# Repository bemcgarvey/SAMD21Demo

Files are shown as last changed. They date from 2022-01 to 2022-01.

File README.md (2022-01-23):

# SAMD21Demo
 
## A demonstartion board for the ATSAMD21G18A microcontroller.  Includes firmware projects to demonstrate many modules and features.  
  
### There is sample firmware for:
* Basic gpio and interrupts
* Sleepwalking
* Analog comparator
* PWM h-bridge control
* USB MSD device
* I2C LCD

### All firmware is built in MPLabX with MPLab Harmony 3 and the XC32 compiler.  
### Schematic and PCB were made with KiCAD

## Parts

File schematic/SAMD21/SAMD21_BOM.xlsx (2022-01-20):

Ref | Qnty | Value | Footprint
C1, C2, C4, C6, | 4 | 100n | Capacitor_SMD:C_0402_1005Metric
C3, | 1 | 10uF | Capacitor_SMD:C_0805_2012Metric
C5, | 1 | 22uF | Capacitor_SMD:C_0603_1608Metric
C7, | 1 | 1 uF | Capacitor_SMD:C_0402_1005Metric
C8, | 1 | 100n | Capacitor_SMD:C_0603_1608Metric
C9, | 1 | 220n | Capacitor_SMD:C_0603_1608Metric
D1, | 1 | Red | LED_SMD:LED_0603_1608Metric
D2, | 1 | Red | LED_SMD:LED_0805_2012Metric
D3, D4, | 2 | MBR0520LT | Diode_SMD:D_SOD-123
D5, | 1 | Yellow | LED_SMD:LED_0805_2012Metric
D6, | 1 | Blue | LED_SMD:LED_0805_2012Metric
D7, | 1 | Green | LED_SMD:LED_0805_2012Metric
D8, | 1 | Green | LED_SMD:LED_0603_1608Metric
D9, | 1 | Yellow | LED_SMD:LED_0603_1608Metric
IC1, | 1 | ATSAMD21G18A-AU | SamacSys_Parts:QFP50P900X900X120-48N
IC2, | 1 | AZ1117IH-3.3TRG1 | SamacSys_Parts:SOT230P700X180-4N
IC3, | 1 | MCP2221-I_SL | SamacSys_Parts:SOIC127P600X175-14N
J1, | 1 | Barrel_Jack_Switch | Connector_BarrelJack:BarrelJack_Wuerth_6941xx301002
J2, | 1 | Power | Connector_PinHeader_2.54mm:PinHeader_2x03_P2.54mm_Vertical
J3, J4, J7, J13, | 4 | Conn_01x02 | Connector_PinHeader_2.54mm:PinHeader_1x02_P2.54mm_Vertical
J5, | 1 | USB_B_Micro | Connector_USB:USB_Micro-B_Amphenol_10118194_Horizontal
J6, | 1 | USB_B_Mini | Connector_USB:USB_Mini-B_Wuerth_65100516121_Horizontal
J8, J9, | 2 | Conn_02x02_Odd_Even | Connector_PinHeader_2.54mm:PinHeader_2x02_P2.54mm_Vertical
J10, J11, J12, | 3 | Conn_02x06_Odd_Even | Connector_PinHeader_2.54mm:PinHeader_2x06_P2.54mm_Vertical
J14, | 1 | Conn_02x05_Odd_Even | Connector_PinHeader_2.54mm:PinHeader_2x05_P2.54mm_Vertical
J15, | 1 | Conn_01x08 | Connector_PinHeader_2.54mm:PinHeader_1x08_P2.54mm_Horizontal
L1, | 1 | 470R | Inductor_SMD:L_0603_1608Metric
R1, | 1 | 100k | Resistor_SMD:R_0603_1608Metric
R2, R5, R6, R8, R11, R12, | 6 | 220R | Resistor_SMD:R_0603_1608Metric
R3, | 1 | 15k | Resistor_SMD:R_0603_1608Metric
R4, | 1 | 22k | Resistor_SMD:R_0603_1608Metric
R7, | 1 | 62R | Resistor_SMD:R_0603_1608Metric
R9, | 1 | 10k | Resistor_SMD:R_0603_1608Metric
R10, R13, | 2 | 4k7 | Resistor_SMD:R_0603_1608Metric
R14, | 1 | 1k | Resistor_SMD:R_0603_1608Metric
SW1, | 1 | SW_MEC_5E | SamacSys_Parts:PTS647SK38SMTR2LFS
SW2, SW3, | 2 | SW_MEC_5E | SamacSys_Parts:FSM16JH

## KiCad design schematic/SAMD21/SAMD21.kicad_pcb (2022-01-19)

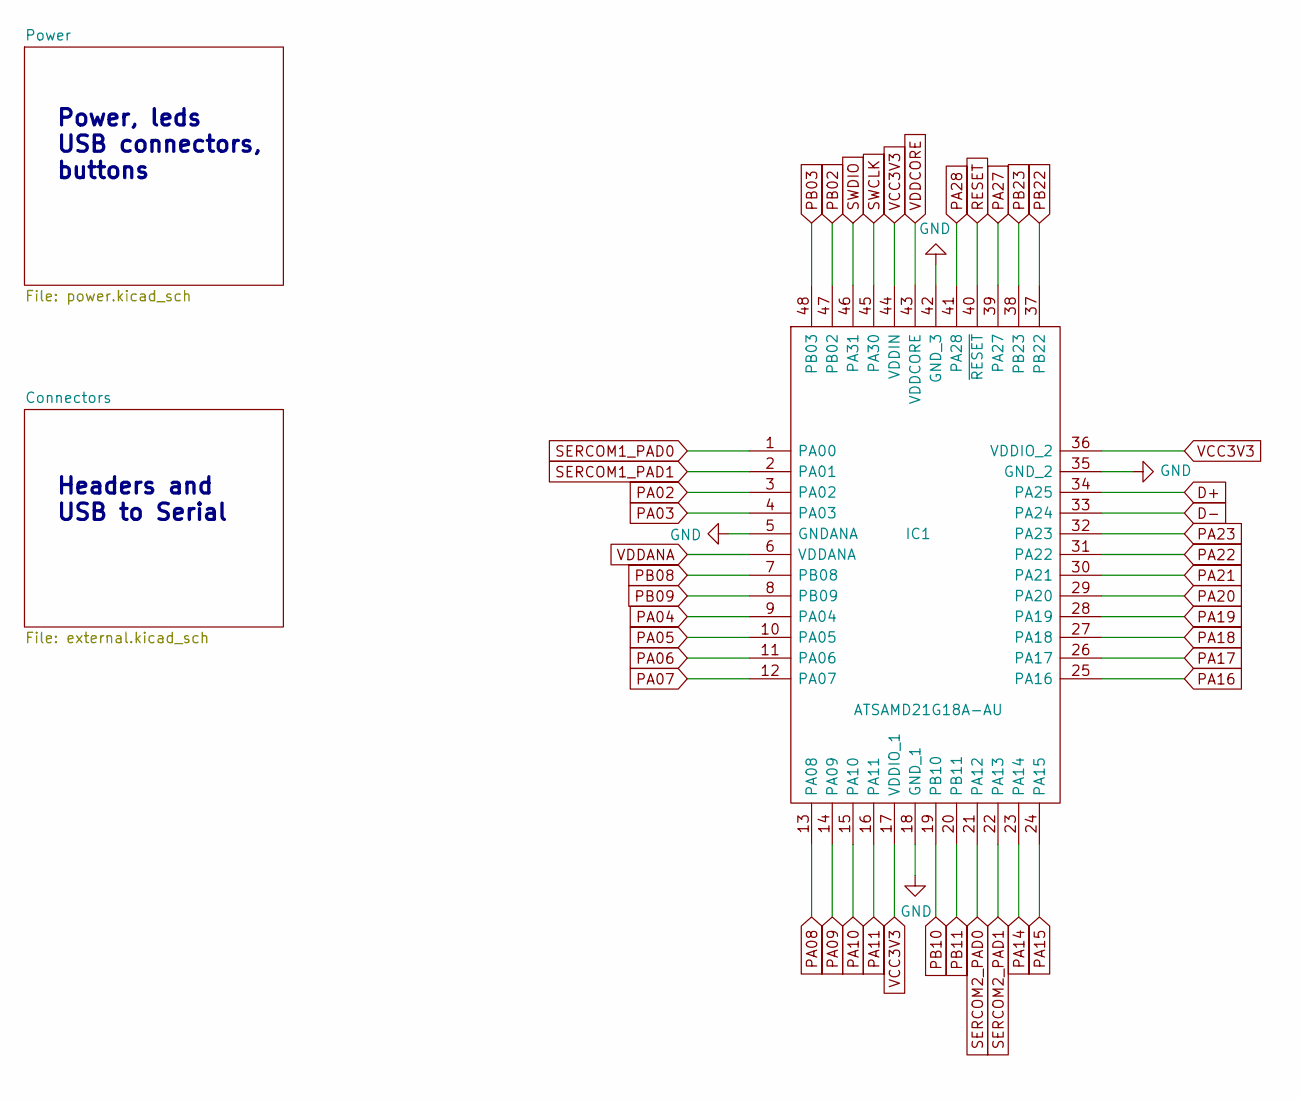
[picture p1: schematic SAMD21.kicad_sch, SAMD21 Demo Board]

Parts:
IC1: ATSAMD21G18A-AU; QFP50P900X900X120-48N; Mouser Part Number 556-ATSAMD21G18A-AU

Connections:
D+: IC1.34 (PA25); also elsewhere on the board
D-: IC1.33 (PA24); also elsewhere on the board
GND: IC1.5 (GNDANA), IC1.18 (GND_1), IC1.35 (GND_2), IC1.42 (GND_3); also elsewhere on the board
PA02: IC1.3 (PA02); also elsewhere on the board
PA03: IC1.4 (PA03); also elsewhere on the board
PA04: IC1.9 (PA04); also elsewhere on the board
PA05: IC1.10 (PA05); also elsewhere on the board
PA06: IC1.11 (PA06); also elsewhere on the board
PA07: IC1.12 (PA07); also elsewhere on the board
PA08: IC1.13 (PA08); also elsewhere on the board
PA09: IC1.14 (PA09); also elsewhere on the board
PA10: IC1.15 (PA10); also elsewhere on the board
PA11: IC1.16 (PA11); also elsewhere on the board
PA14: IC1.23 (PA14); also elsewhere on the board
PA15: IC1.24 (PA15); also elsewhere on the board
PA16: IC1.25 (PA16); also elsewhere on the board
PA17: IC1.26 (PA17); also elsewhere on the board
PA18: IC1.27 (PA18); also elsewhere on the board
PA19: IC1.28 (PA19); also elsewhere on the board
PA20: IC1.29 (PA20); also elsewhere on the board
PA21: IC1.30 (PA21); also elsewhere on the board
PA22: IC1.31 (PA22); also elsewhere on the board
PA23: IC1.32 (PA23); also elsewhere on the board
PA27: IC1.39 (PA27); also elsewhere on the board
PA28: IC1.41 (PA28); also elsewhere on the board
PB02: IC1.47 (PB02); also elsewhere on the board
PB03: IC1.48 (PB03); also elsewhere on the board
PB08: IC1.7 (PB08); also elsewhere on the board
PB09: IC1.8 (PB09); also elsewhere on the board
PB10: IC1.19 (PB10); also elsewhere on the board
PB11: IC1.20 (PB11); also elsewhere on the board
PB22: IC1.37 (PB22); also elsewhere on the board
PB23: IC1.38 (PB23); also elsewhere on the board
RESET: IC1.40 (~RESET); also elsewhere on the board
SERCOM1_PAD0: IC1.1 (PA00); also elsewhere on the board
SERCOM1_PAD1: IC1.2 (PA01); also elsewhere on the board
SERCOM2_PAD0: IC1.21 (PA12); also elsewhere on the board
SERCOM2_PAD1: IC1.22 (PA13); also elsewhere on the board
SWCLK: IC1.45 (PA30); also elsewhere on the board
SWDIO: IC1.46 (PA31); also elsewhere on the board
VCC3V3: IC1.17 (VDDIO_1), IC1.36 (VDDIO_2), IC1.44 (VDDIN); also elsewhere on the board
VDDANA: IC1.6 (VDDANA); also elsewhere on the board
VDDCORE: IC1.43 (VDDCORE); also elsewhere on the board

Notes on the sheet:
Headers and USB to Serial
Power, leds USB connectors, buttons

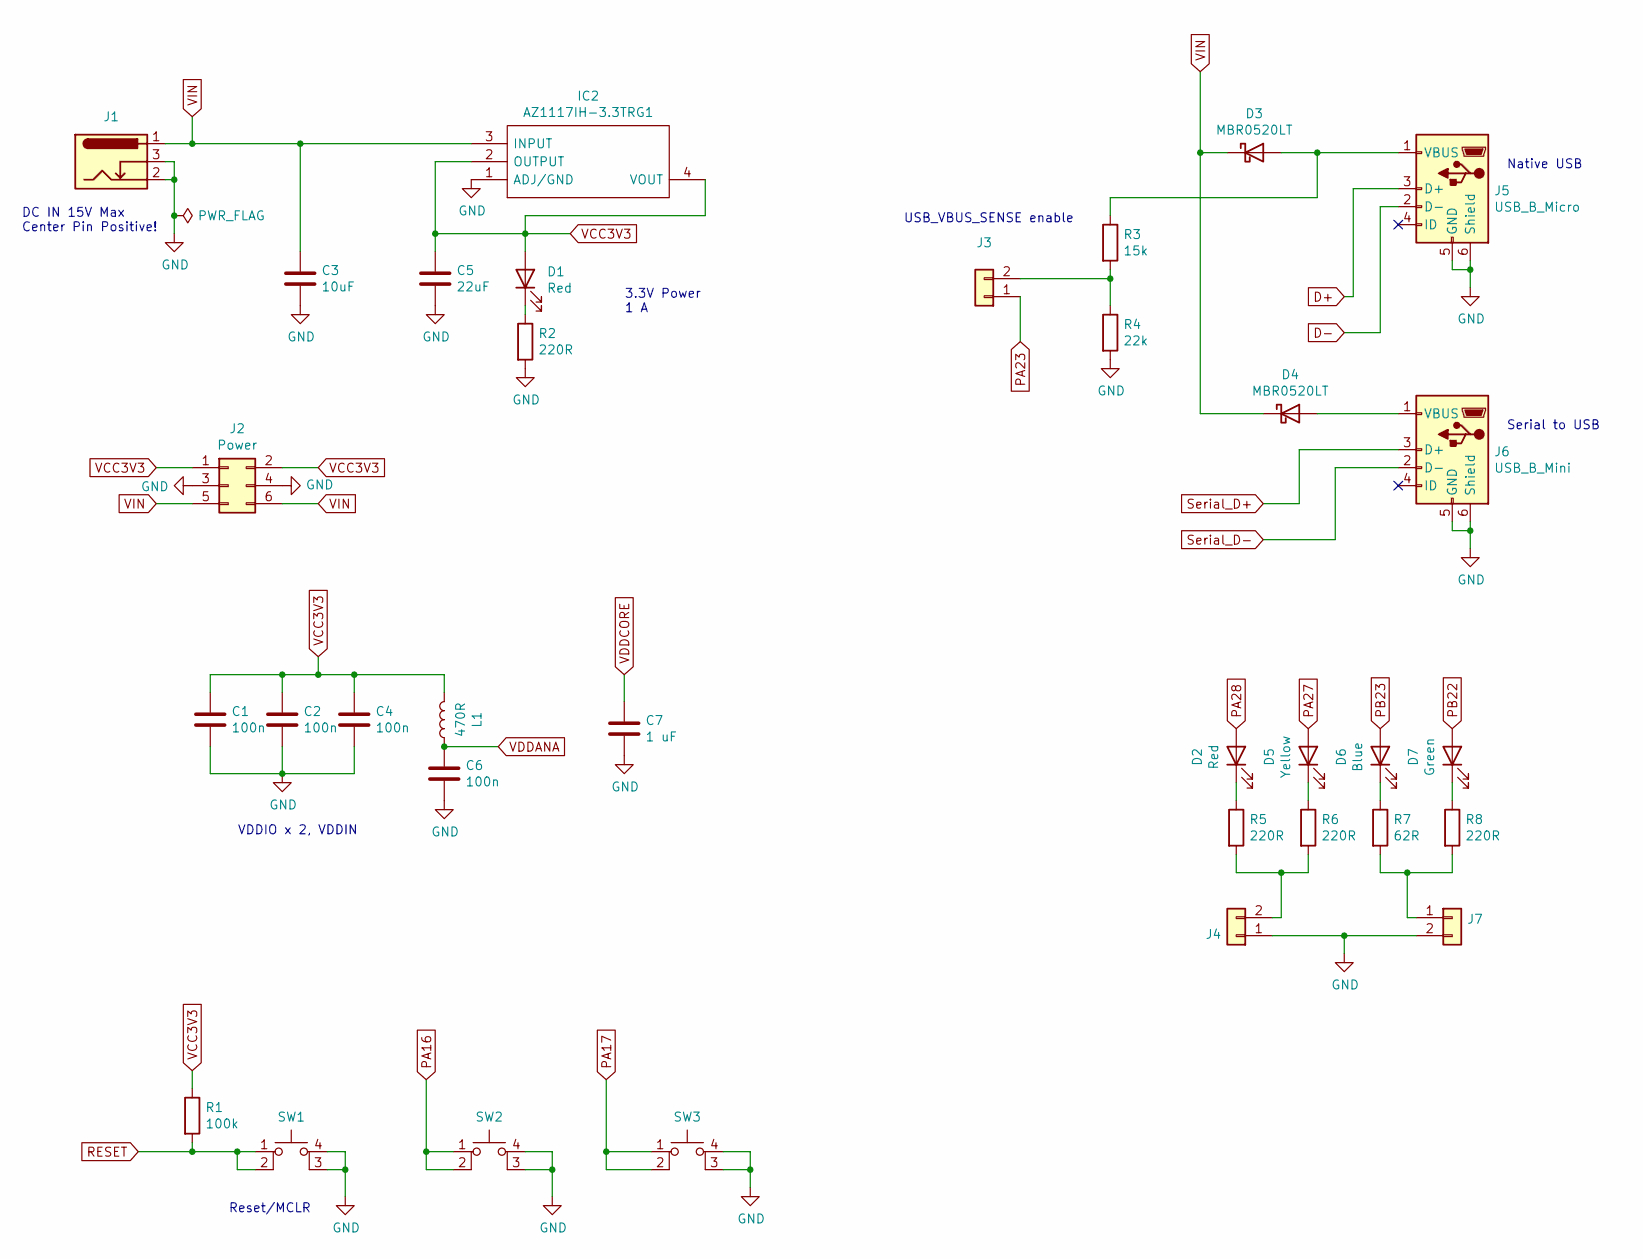
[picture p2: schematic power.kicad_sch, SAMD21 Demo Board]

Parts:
C1, C2, C4, C6: 100n; C_0402_1005Metric
C3: 10uF; C_0805_2012Metric
C5: 22uF; C_0603_1608Metric
C7: 1 uF; C_0402_1005Metric
D1: Red; LED_0603_1608Metric
D2: Red; LED_0805_2012Metric
D3, D4: MBR0520LT; D_SOD-123
D5: Yellow; LED_0805_2012Metric
D6: Blue; LED_0805_2012Metric
D7: Green; LED_0805_2012Metric
IC2: AZ1117IH-3.3TRG1; SOT230P700X180-4N; Mouser Part Number 621-AZ1117IH-3.3TRG1
J1: Barrel_Jack_Switch; BarrelJack_Wuerth_6941xx301002
J2: Power; PinHeader_2x03_P2.54mm_Vertical
J3, J4, J7: Conn_01x02; PinHeader_1x02_P2.54mm_Vertical
J5: USB_B_Micro; USB_Micro-B_Amphenol_10118194_Horizontal
J6: USB_B_Mini; USB_Mini-B_Wuerth_65100516121_Horizontal
L1: 470R; L_0603_1608Metric
R1: 100k; R_0603_1608Metric
R2, R5, R6, R8: 220R; R_0603_1608Metric
R3: 15k; R_0603_1608Metric
R4: 22k; R_0603_1608Metric
R7: 62R; R_0603_1608Metric
SW1: SW_MEC_5E; PTS647SK38SMTR2LFS
SW2, SW3: SW_MEC_5E; FSM16JH

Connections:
D+: J5.3 (D+); also elsewhere on the board
D-: J5.2 (D-); also elsewhere on the board
GND: C1.2, C2.2, C3.2, C4.2, C5.2, C6.2, C7.2, IC2.1 (ADJ/GND), J1.2, J1.3, J2.3, J2.4, J4.1, J5.5 (GND), J5.6 (Shield), J6.5 (GND), J6.6 (Shield), J7.2, R2.2, R4.2, SW1.3 (K), SW1.4 (A), SW2.3 (K), SW2.4 (A), SW3.3 (K), SW3.4 (A); also elsewhere on the board
unnamed: D1.1 (K), R2.1
unnamed: D2.1 (K), R5.1
unnamed: D3.2 (A), J5.1 (VBUS), R3.1
unnamed: D4.2 (A), J6.1 (VBUS)
unnamed: D5.1 (K), R6.1
unnamed: D6.1 (K), R7.1
unnamed: D7.1 (K), R8.1
unnamed: J3.2, R3.2, R4.1
unnamed: J4.2, R5.2, R6.2
unnamed: J7.1, R7.2, R8.2
PA16: SW2.1, SW2.2; also elsewhere on the board
PA17: SW3.1, SW3.2; also elsewhere on the board
PA23: J3.1; also elsewhere on the board
PA27: D5.2 (A); also elsewhere on the board
PA28: D2.2 (A); also elsewhere on the board
PB22: D7.2 (A); also elsewhere on the board
PB23: D6.2 (A); also elsewhere on the board
RESET: R1.2, SW1.1, SW1.2; also elsewhere on the board
Serial_D+: J6.3 (D+); also elsewhere on the board
Serial_D-: J6.2 (D-); also elsewhere on the board
VCC3V3: C1.1, C2.1, C4.1, C5.1, D1.2 (A), IC2.2 (OUTPUT), IC2.4 (VOUT), J2.1, J2.2, L1.2, R1.1; also elsewhere on the board
VDDANA: C6.1, L1.1; also elsewhere on the board
VDDCORE: C7.1; also elsewhere on the board
VIN: C3.1, D3.1 (K), D4.1 (K), IC2.3 (INPUT), J1.1, J2.5, J2.6

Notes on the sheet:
3.3V Power 1 A
Reset/MCLR
VDDIO x 2, VDDIN
Serial to USB
USB_VBUS_SENSE enable
DC IN 15V Max Center Pin Positive!
Native USB

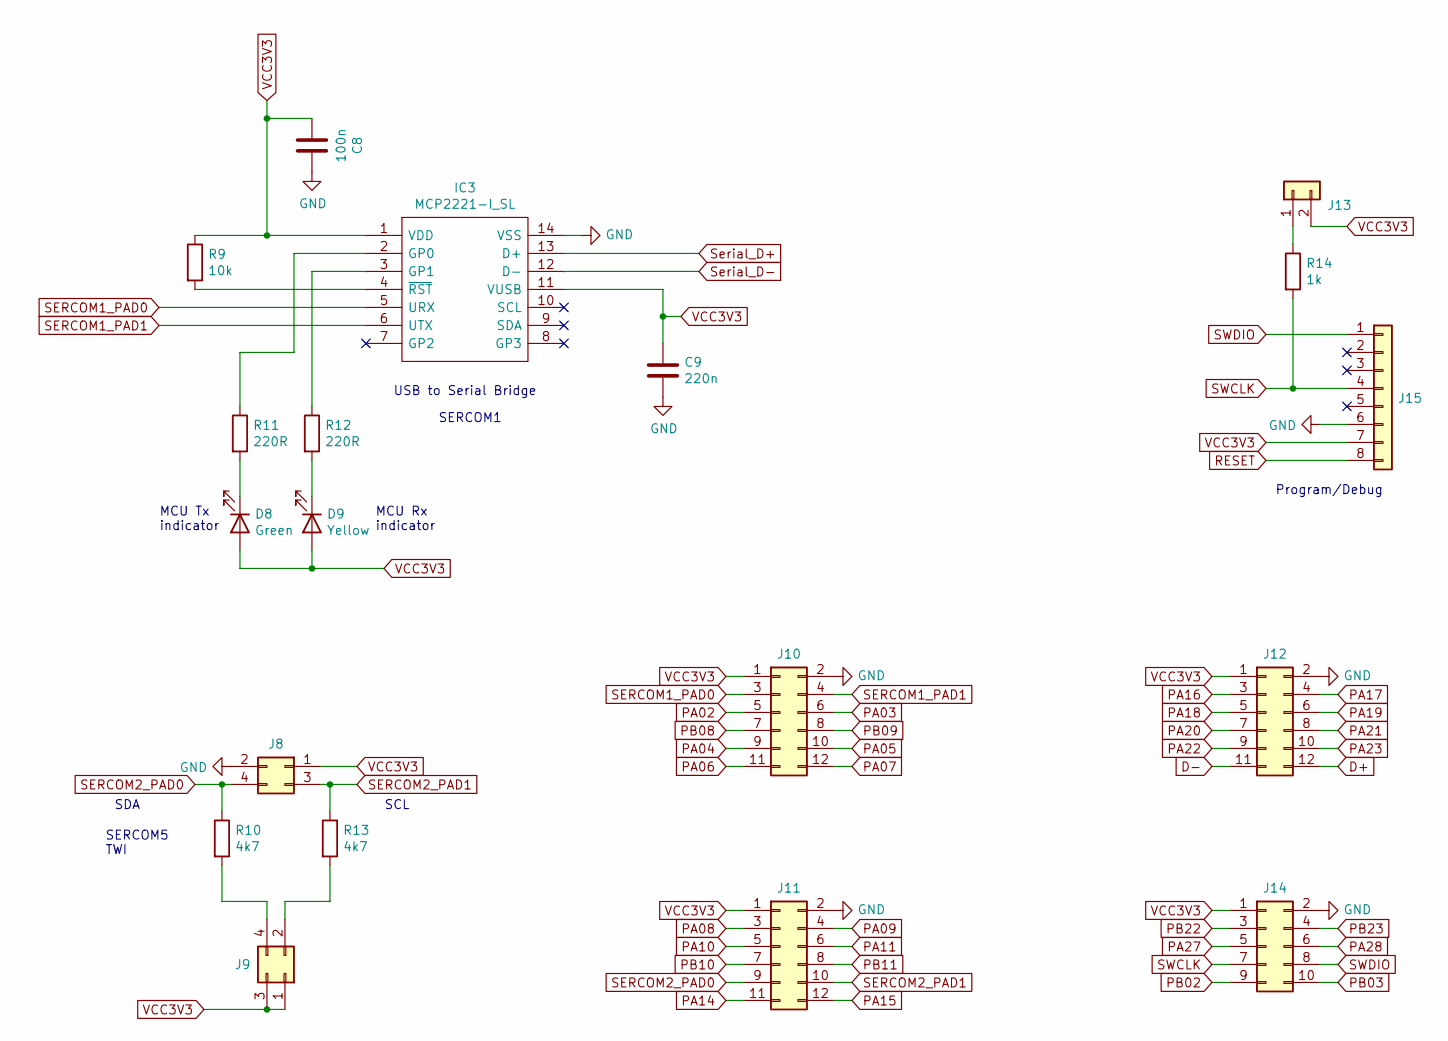
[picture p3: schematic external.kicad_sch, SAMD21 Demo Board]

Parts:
C8: 100n; C_0603_1608Metric
C9: 220n; C_0603_1608Metric
D8: Green; LED_0603_1608Metric
D9: Yellow; LED_0603_1608Metric
IC3: MCP2221-I_SL; SOIC127P600X175-14N; Mouser Part Number 579-MCP2221-I/SL
J8, J9: Conn_02x02_Odd_Even; PinHeader_2x02_P2.54mm_Vertical
J10, J11, J12: Conn_02x06_Odd_Even; PinHeader_2x06_P2.54mm_Vertical
J13: Conn_01x02; PinHeader_1x02_P2.54mm_Vertical
J14: Conn_02x05_Odd_Even; PinHeader_2x05_P2.54mm_Vertical
J15: Conn_01x08; PinHeader_1x08_P2.54mm_Horizontal
R9: 10k; R_0603_1608Metric
R10, R13: 4k7; R_0603_1608Metric
R11, R12: 220R; R_0603_1608Metric
R14: 1k; R_0603_1608Metric

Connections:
D+: J12.12; also elsewhere on the board
D-: J12.11; also elsewhere on the board
GND: C8.1, C9.2, IC3.14 (VSS), J8.2, J10.2, J11.2, J12.2, J14.2, J15.6; also elsewhere on the board
unnamed: D8.1 (K), R11.2
unnamed: D9.1 (K), R12.2
unnamed: IC3.2 (GP0), R11.1
unnamed: IC3.3 (GP1), R12.1
unnamed: IC3.4 (~RST), R9.2
unnamed: J9.2, R13.2
unnamed: J9.4, R10.2
unnamed: J13.1, R14.1
PA02: J10.5; also elsewhere on the board
PA03: J10.6; also elsewhere on the board
PA04: J10.9; also elsewhere on the board
PA05: J10.10; also elsewhere on the board
PA06: J10.11; also elsewhere on the board
PA07: J10.12; also elsewhere on the board
PA08: J11.3; also elsewhere on the board
PA09: J11.4; also elsewhere on the board
PA10: J11.5; also elsewhere on the board
PA11: J11.6; also elsewhere on the board
PA14: J11.11; also elsewhere on the board
PA15: J11.12; also elsewhere on the board
PA16: J12.3; also elsewhere on the board
PA17: J12.4; also elsewhere on the board
PA18: J12.5; also elsewhere on the board
PA19: J12.6; also elsewhere on the board
PA20: J12.7; also elsewhere on the board
PA21: J12.8; also elsewhere on the board
PA22: J12.9; also elsewhere on the board
PA23: J12.10; also elsewhere on the board
PA27: J14.5; also elsewhere on the board
PA28: J14.6; also elsewhere on the board
PB02: J14.9; also elsewhere on the board
PB03: J14.10; also elsewhere on the board
PB08: J10.7; also elsewhere on the board
PB09: J10.8; also elsewhere on the board
PB10: J11.7; also elsewhere on the board
PB11: J11.8; also elsewhere on the board
PB22: J14.3; also elsewhere on the board
PB23: J14.4; also elsewhere on the board
RESET: J15.8; also elsewhere on the board
SERCOM1_PAD0: IC3.5 (URX), J10.3; also elsewhere on the board
SERCOM1_PAD1: IC3.6 (UTX), J10.4; also elsewhere on the board
SERCOM2_PAD0: J8.4, J11.9, R10.1; also elsewhere on the board
SERCOM2_PAD1: J8.3, J11.10, R13.1; also elsewhere on the board
SWCLK: J14.7, J15.4, R14.2; also elsewhere on the board
SWDIO: J14.8, J15.1; also elsewhere on the board
Serial_D+: IC3.13 (D+); also elsewhere on the board
Serial_D-: IC3.12 (D-); also elsewhere on the board
VCC3V3: C8.2, C9.1, D8.2 (A), D9.2 (A), IC3.1 (VDD), IC3.11 (VUSB), J8.1, J9.1, J9.3, J10.1, J11.1, J12.1, J13.2, J14.1, J15.7, R9.1; also elsewhere on the board

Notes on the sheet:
MCU Tx indicator
SCL
USB to Serial Bridge
SDA
MCU Rx indicator
SERCOM5 TWI
Program/Debug
SERCOM1

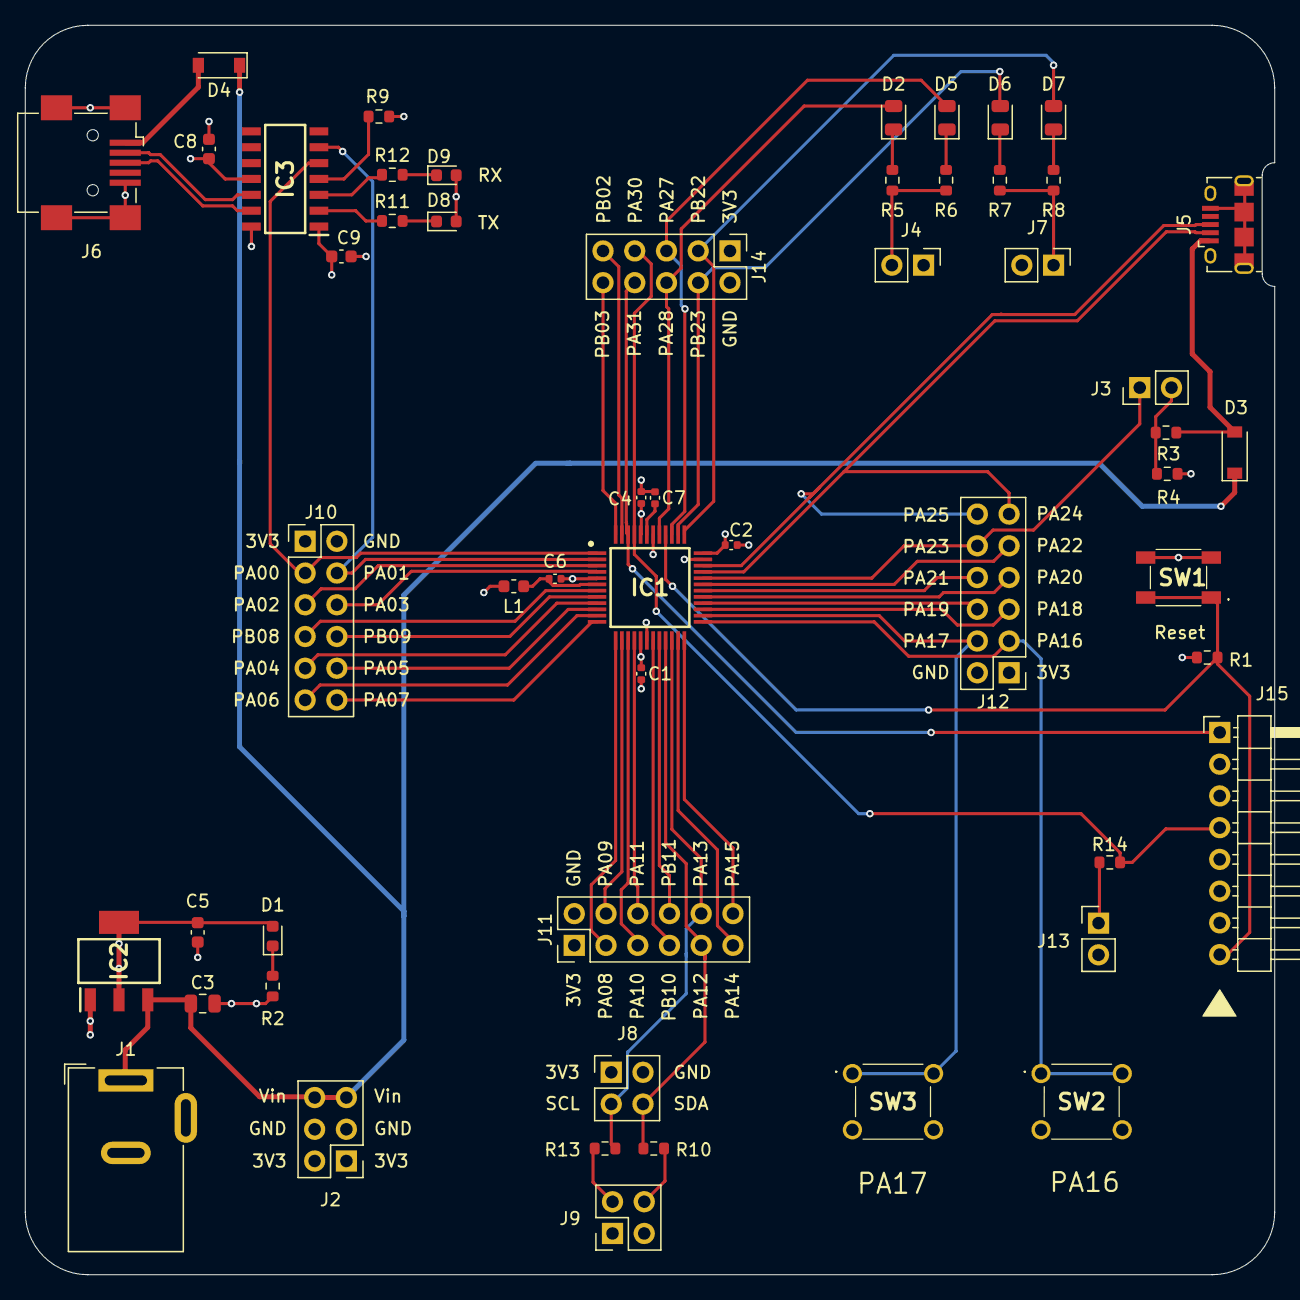
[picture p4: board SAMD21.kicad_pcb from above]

Board: 4 copper layers, 100.0 x 100.0 mm, 54 parts (0 on the bottom side), 64 nets.

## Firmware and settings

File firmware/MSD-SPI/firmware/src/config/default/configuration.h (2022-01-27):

/*******************************************************************************
  System Configuration Header

  File Name:
    configuration.h

  Summary:
    Build-time configuration header for the system defined by this project.

  Description:
    An MPLAB Project may have multiple configurations.  This file defines the
    build-time options for a single configuration.

  Remarks:
    This configuration header must not define any prototypes or data
    definitions (or include any files that do).  It only provides macro
    definitions for build-time configuration options

*******************************************************************************/

// DOM-IGNORE-BEGIN
/*******************************************************************************
* Copyright (C) 2018 Microchip Technology Inc. and its subsidiaries.
*
* Subject to your compliance with these terms, you may use Microchip software
* and any derivatives exclusively with Microchip products. It is your
* responsibility to comply with third party license terms applicable to your
* use of third party software (including open source software) that may
* accompany Microchip software.
*
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
* IN NO EVENT WILL MICROCHIP BE LIABLE FOR ANY INDIRECT, SPECIAL, PUNITIVE,
* INCIDENTAL OR CONSEQUENTIAL LOSS, DAMAGE, COST OR EXPENSE OF ANY KIND
* WHATSOEVER RELATED TO THE SOFTWARE, HOWEVER CAUSED, EVEN IF MICROCHIP HAS
* BEEN ADVISED OF THE POSSIBILITY OR THE DAMAGES ARE FORESEEABLE. TO THE
* FULLEST EXTENT ALLOWED BY LAW, MICROCHIP'S TOTAL LIABILITY ON ALL CLAIMS IN
* ANY WAY RELATED TO THIS SOFTWARE WILL NOT EXCEED THE AMOUNT OF FEES, IF ANY,
* THAT YOU HAVE PAID DIRECTLY TO MICROCHIP FOR THIS SOFTWARE.
*******************************************************************************/
// DOM-IGNORE-END

#ifndef CONFIGURATION_H
#define CONFIGURATION_H

// *****************************************************************************
// *****************************************************************************
// Section: Included Files
// *****************************************************************************
// *****************************************************************************
/*  This section Includes other configuration headers necessary to completely
    define this configuration.
*/

#include "user.h"
#include "device.h"

// DOM-IGNORE-BEGIN
#ifdef __cplusplus  // Provide C++ Compatibility

extern "C" {

#endif
// DOM-IGNORE-END

// *****************************************************************************
// *****************************************************************************
// Section: System Configuration
// *****************************************************************************
// *****************************************************************************



// *****************************************************************************
// *****************************************************************************
// Section: System Service Configuration
// *****************************************************************************
// *****************************************************************************


// *****************************************************************************
// *****************************************************************************
// Section: Driver Configuration
// *****************************************************************************
// *****************************************************************************
/* Memory Driver Global Configuration Options */
#define DRV_MEMORY_INSTANCES_NUMBER          1

/* Memory Driver Instance 0 Configuration */
#define DRV_MEMORY_INDEX_0                   0
#define DRV_MEMORY_CLIENTS_NUMBER_IDX0       1
#define DRV_MEMORY_BUFFER_QUEUE_SIZE_IDX0    1


/* AT25M Driver Configuration Options */
#define DRV_AT25_INSTANCES_NUMBER              1
#define DRV_AT25_INDEX                         0
#define DRV_AT25_CLIENTS_NUMBER_IDX            1
#define DRV_AT25_INT_SRC_IDX                   SERCOM0_IRQn
#define DRV_AT25_EEPROM_FLASH_SIZE             131072
#define DRV_AT25_EEPROM_PAGE_SIZE              256
#define DRV_AT25_CHIP_SELECT_PIN_IDX           SYS_PORT_PIN_PA07
#define DRV_AT25_HOLD_PIN_IDX                  SYS_PORT_PIN_PA08
#define DRV_AT25_WP_PIN_IDX                    SYS_PORT_PIN_PA09


// *****************************************************************************
// *****************************************************************************
// Section: Middleware & Other Library Configuration
// *****************************************************************************
// *****************************************************************************
/* Number of Endpoints used */
#define DRV_USBFSV1_ENDPOINTS_NUMBER                        2

/* The USB Device Layer will not initialize the USB Driver */
#define USB_DEVICE_DRIVER_INITIALIZE_EXPLICIT
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

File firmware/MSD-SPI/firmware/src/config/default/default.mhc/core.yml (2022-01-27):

format_version: v1.0
type: UniqueComponent
attributes: {id: core}
children:
- type: Symbols
  children:
  - type: KeyValueSet
    attributes: {id: COMPILER_CHOICE}
    children:
    - type: Values
      children:
      - type: Dynamic
        attributes: {id: core, value: '0'}
  - type: Boolean
    attributes: {id: CONFIG_CLOCK_DFLL_ENABLE}
    children:
    - type: Values
      children:
      - type: Dynamic
        attributes: {id: core, value: 'true'}
  - type: Integer
    attributes: {id: CONFIG_CLOCK_DFLL_FINE}
    children:
    - type: Values
      children:
      - type: User
        attributes: {value: '10'}
  - type: Integer
    attributes: {id: CONFIG_CLOCK_DFLL_MUL}
    children:
    - type: Values
      children:
      - type: User
        attributes: {value: '48000'}
  - type: KeyValueSet
    attributes: {id: CONFIG_CLOCK_DFLL_OPMODE}
    children:
    - type: Values
      children:
      - type: User
        attributes: {value: '1'}
  - type: Boolean
    attributes: {id: CONFIG_CLOCK_DFLL_USB}
    children:
    - type: Values
      children:
      - type: User
        attributes: {value: 'true'}
  - type: Boolean
    attributes: {id: CONFIG_CLOCK_OSC8M_ENABLE}
    children:
    - type: Values
      children:
      - type: Dynamic
        attributes: {id: core, value: 'false'}
  - type: Integer
    attributes: {id: CPU_CLOCK_FREQUENCY}
    children:
    - type: Values
      children:
      - type: Dynamic
        attributes: {id: core, value: '48000000'}
  - type: Menu
    attributes: {id: CoreIARMenu}
    children:
    - type: Attributes
      children:
      - type: Boolean
        attributes: {id: visible}
        children:
        - {type: Value, value: 'false'}
  - type: Menu
    attributes: {id: CoreKEILMenu}
    children:
    - type: Attributes
      children:
      - type: Boolean
        attributes: {id: visible}
        children:
        - {type: Value, value: 'false'}
  - type: KeyValueSet
    attributes: {id: DEVICE_BOD33_ACTION}
    children:
    - type: Values
      children:
      - type: Dynamic
        attributes: {id: core, value: '1'}
  - type: KeyValueSet
    attributes: {id: DEVICE_BOD33_EN}
    children:
    - type: Values
      children:
      - type: Dynamic
        attributes: {id: core, value: '1'}
  - type: KeyValueSet
    attributes: {id: DEVICE_BOD33_HYST}
    children:
    - type: Values
      children:
      - type: Dynamic
        attributes: {id: core, value: '0'}
  - type: KeyValueSet
    attributes: {id: DEVICE_SECURITY_CMD}
    children:
    - type: Values
      children:
      - type: Dynamic
        attributes: {id: core, value: '0'}
  - type: KeyValueSet
    attributes: {id: DEVICE_WDT_ALWAYSON}
    children:
    - type: Values
      children:
      - type: Dynamic
        attributes: {id: core, value: '0'}
  - type: KeyValueSet
    attributes: {id: DEVICE_WDT_ENABLE}
    children:
    - type: Values
      children:
      - type: Dynamic
        attributes: {id: core, value: '0'}
  - type: KeyValueSet
    attributes: {id: DEVICE_WDT_WEN}
    children:
    - type: Values
      children:
      - type: Dynamic
        attributes: {id: core, value: '0'}
  - type: KeyValueSet
    attributes: {id: DEVICE_WDT_WINDOW_0}
    children:
    - type: Values
      children:
      - type: Dynamic
        attributes: {id: core, value: '1'}
  - type: Hex
    attributes: {id: DEVICE_WDT_WINDOW_1}
    children:
    - type: Values
      children:
      - type: Dynamic
        attributes: {id: core, value: '4'}
  - type: Integer
    attributes: {id: DFLL_CLOCK_FREQ}
    children:
    - type: Values
      children:
      - type: Dynamic
        attributes: {id: core, value: '48000000'}
  - type: Integer
    attributes: {id: DPLL_CLOCK_FREQ}
    children:
    - type: Values
      children:
      - type: Dynamic
        attributes: {id: core, value: '0'}
  - type: Integer
    attributes: {id: GCLK_0_FREQ}
    children:
    - type: Values
      children:
      - type: Dynamic
        attributes: {id: core, value: '48000000'}
  - type: KeyValueSet
    attributes: {id: GCLK_0_SRC}
    children:
    - type: Values
      children:
      - type: Dynamic
        attributes: {id: core, value: '7'}
  - type: Integer
    attributes: {id: GCLK_1_FREQ}
    children:
    - type: Values
      children:
      - type: Dynamic
        attributes: {id: core, value: '0'}
  - type: Integer
    attributes: {id: GCLK_2_FREQ}
    children:
    - type: Values
      children:
      - type: Dynamic
        attributes: {id: core, value: '0'}
  - type: Integer
    attributes: {id: GCLK_3_FREQ}
    children:
    - type: Values
      children:
      - type: Dynamic
        attributes: {id: core, value: '0'}
  - type: Integer
    attributes: {id: GCLK_4_FREQ}
    children:
    - type: Values
      children:
      - type: Dynamic
        attributes: {id: core, value: '0'}
  - type: Integer
    attributes: {id: GCLK_5_FREQ}
    children:
    - type: Values
      children:
      - type: Dynamic
        attributes: {id: core, value: '0'}
  - type: Integer
    attributes: {id: GCLK_6_FREQ}
    children:
    - type: Values
      children:
      - type: Dynamic
        attributes: {id: core, value: '0'}
  - type: Integer
    attributes: {id: GCLK_7_FREQ}
    children:
    - type: Values
      children:
      - type: Dynamic
        attributes: {id: core, value: '0'}
  - type: Integer
    attributes: {id: GCLK_8_FREQ}
    children:
    - type: Values
      children:
      - type: Dynamic
        attributes: {id: core, value: '0'}
  - type: ListEntry
    attributes: {id: GCLK_CODE}
    children:
    - type: Attributes
      children:
      - type: StringArray
        attributes: {id: values}
        children:
        - type: Values
          children:
          - {type: Value, value: '    DFLL_Initialize();'}
          - {type: Value, value: '    GCLK0_Initialize();'}
  - type: Boolean
    attributes: {id: GCLK_CYCLE_FORMED}
    children:
    - type: Values
      children:
      - type: Dynamic
        attributes: {id: core, value: 'false'}
  - type: Boolean
    attributes: {id: GCLK_ID_20_CHEN}
    children:
    - type: Values
      children:
      - type: Dynamic
        attributes: {id: core, value: 'true'}
  - type: Integer
    attributes: {id: GCLK_ID_20_FREQ}
    children:
    - type: Values
      children:
      - type: Dynamic
        attributes: {id: core, value: '48000000'}
  - type: Boolean
    attributes: {id: GCLK_ID_6_CHEN}
    children:
    - type: Values
      children:
      - type: Dynamic
        attributes: {id: core, value: 'true'}
      - type: User
        attributes: {value: 'true'}
  - type: Integer
    attributes: {id: GCLK_ID_6_FREQ}
    children:
    - type: Values
      children:
      - type: Dynamic
        attributes: {id: core, value: '48000000'}
  - type: Integer
    attributes: {id: GCLK_IO_0_FREQ}
    children:
    - type: Values
      children:
      - type: Dynamic
        attributes: {id: core, value: '0'}
  - type: Integer
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

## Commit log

2021-11-14 Initial project
    [SAMD21.kicad_pcb, SAMD21.sch]
2021-11-16 Partial schematic
    [SAMD21.sch, external.sch, power.sch]
2021-11-17 Complete schematic
    [SAMD21.sch, external.sch, power.sch]
2021-11-17 Moved I2C to pins with support for I2C
    [SAMD21.sch, external.sch, power.sch]
2021-11-20 Initial pcb layout
    [SAMD21.kicad_pcb]
2021-11-25 Minor trace adjustments and some labels
    [SAMD21.kicad_pcb]
2021-11-27 Finished silkscreen
    [SAMD21.kicad_pcb]
2021-11-28 Changed LEDs to 0805
    [SAMD21.kicad_pcb, power.sch]
2022-01-02 minor fix
    [SAMD21.kicad_pcb, SAMD21.sch]
2022-01-02 Changed USB micro footprint
    [SAMD21.kicad_pcb, power.sch]
2022-01-02 Generated gerbers
    [SAMD21-B_Cu.gbl, SAMD21-B_Mask.gbs, SAMD21-B_SilkS.gbo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]
2022-01-19 Converted to KiCad 6
    [SAMD21.kicad_pcb, SAMD21.kicad_sch, SAMD21.sch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]
2022-01-20 Added BOM
    [SAMD21_BOM.xlsx]
2022-01-21 Added lcd
    [configuration.h]
2022-01-22 Added MSD demo
    [configuration.h]
2022-01-23 Added TCC h-bridge pwm
2022-01-24 Added SPI eeprom demo
    [configuration.h]
2022-01-27 Added MSD with SPI eeprom demo
    [configuration.h]
